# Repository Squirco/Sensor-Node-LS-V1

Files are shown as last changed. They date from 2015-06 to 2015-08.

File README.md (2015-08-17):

#Squirco Sensor Network Light Switch

Hardware files for Squirco Sensor Network Light Switch, as seen on Hackaday here:  
https://hackaday.io/project/3321-squirco-smart-home-system-sensor-network  
  
#Repository Contents
* **/Hardware-Main** - Eagle design files for the Logic and Power Supply boards (.sch and .brd)
* **/Hardware-Addon** - Eagle design files for the button, sensor, and programming adaptor boards (.sch and .brd)
* **/Hardware-3D** - 3D files for the enclosure. Designed to be 3D printed, tested with Form1+ and Shapeways/Sculpteo
* **/Hardware-Extras** - Contains BOM and other documents
* **/Firmware** - contains firmware files
  
#License Information
The hardware is released under <a href = "https://creativecommons.org/licenses/by-sa/4.0/">CC BY-SA 4.0</a>  
Hardware authors: Original Design by Steven @ Squirco
Distributed as-is; no warranty is given

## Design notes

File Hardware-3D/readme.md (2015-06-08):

#Squirco Sensor Network Light Switch
3D files are for the Open Edition, which are designed to be 3D printed  
Printed are tested with the following 3D printers and 3D printing services:
*formlabs Form1+
*Shapeways
*Sculpteo

Your mileage may vary depending on the 3D printer used. Parts can be purchased from Shapeways at a later date.

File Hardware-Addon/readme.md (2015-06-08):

#Squirco Sensor Light Switch Addons
Button board is designed for 1.6mm thickness. Ambient light sensor board is designed for 1.6mm thickness or below, ideally as thin as possible.

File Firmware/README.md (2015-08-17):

#Squirco Sensor Network Light Switch

Firmware files for Squirco Sensor Network Light Switch as a Atmel Studio 6 Project.

#Release Notes
- v0.5b
Initial commit after re-write from v0.4c. Some features have been re-written to work more efficiently. Some features have been removed for further re-write.

Working features:
- Light switch control, both hardware and from remote software
- Temperature measurement
- Ambient light measurement
- Networking and System Join Chain

Features to be re-implemented:
- on-device sync mode
- LED control
- Presence Detection

Features under experimentation
- OTA update

Further documentation will be added in time.

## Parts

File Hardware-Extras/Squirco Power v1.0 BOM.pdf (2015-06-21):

Squirco Power BOM
Count | Part Name | Value | Description | Size | Part Number | MFR
3 D1 D2 D3 | RS1KB-‐13-‐F | DIODE GEN PURP 800V 1A SMB | SMB | RS1KB-‐13-‐F | Diodes
1 F1 | FUSE BOARD MNT 1A 250VAC 125VDC | 10.10mm x 3.00mm 3403.0166.11 | Schurter
1 J1* | Micro USB connector | std
1 JP2 | CONN TERM BLOCK 3POS 5MM STR PCB | 1825970000 | Weidmuller
1 P1 | 3W AC-‐DC Converter | VTX-‐214-‐003-‐105 | Vigortronix
1 Q1 | BSS138 | MOSFET N-‐CH 50V 220MA SOT-‐23 | SOT23 | BSS138 | std
1 R11 | 39 | RES SMD 39 OHM 1% 1/10W 0603 | 0603 | std | std
1 S1 | ALQ305 | RELAY GEN PURPOSE SPST 10A 5V | ALQ305 | Panasonic
3 SC1 | P1 P2 P4 | MICRO UNIVERSAL CONTACT Z 4.0MM | 120220-‐0315 | ITT Cannon

Notes:
1. J1 is only needed for development prototypes as an alternate power source

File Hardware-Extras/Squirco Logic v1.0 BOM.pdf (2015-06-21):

Squirco Logic BOM
Count | Part Name | Value | Description | Size | Part Number | MFR
1 B1 | BALUN | Impedance matched Balun for ATMEGARFR2 | 2mm x 1.25mm 2450BM15A0015E | Johanson
1 B2 | BALUN | Impedance matched Balun for CC2541 | 2mm x 1.25mm 2450BM15A0002E | Johanson
4 C10 C13 C15 C21 12pF | CAP CER 12PF 50V 5% NPO 0402 | 0402 | std | std
2 C8 C12 | 22pF | CAP CER 22PF 50V 5% NPO 0402 | 0402 | std | std
1 C16 | 1nF | MLCC -‐ SMD/SMT 0603 1000pF 50V X7R 10% | 0603 | std | std
1 C6 | 10nF | MLCC -‐ SMD/SMT 0603 0.01uF 50V X7R 10% | 0603 | std | std
1 C2 | 0.1uF | MLCC -‐ SMD/SMT 0603 0.1uF 25V X7R 10% | 0603 | std | std
4 C1 C7 C14 C20 | 1uF | MLCC -‐ SMD/SMT 1.0UF 16V 10% | 0603 | std | std
3 C3 C5 C9 | 2.2uF | MLCC -‐ SMD/SMT 2.2UF 6.3V 10% | 0603 | std | std
1 C4 | DNI
1 D1 | WS2812B | Addressable RGB LED | 5050 | WS2812B | Worldsemi
1 LED1* | LED0805 | Power indicating LED (red) | 0805 | std | std
2 R1 R12 | 0R | 0R resistor | 0402 | std | std
1 R15 | 2k7 | SMD 1/10watt 2.7Kohms 1% | 0603 | std | std
2 R3 R8 | 4k7 | SMD 1/10watt 4.7Kohms 1% | 0603 | std | std
1 R14 | 10k | SMD 1/10watts 10Kohms 1% | 0603 | std | std
1 R9 | 56k | SMD 1/10watts 56Kohms 1% | 0603 | std | std
1 R4* | 510 current limiting resistor for LED1 | 0603 | std | std
1 R7 | 10k NTC | NTC 10K OHM 1% | 0402 | NCP15XH103F03RC | Murata
4 R2 R10 R11 R13 DNI | Footprints for RF filter passives | 0402 | std | std
1 IC1 | LP2985 | LDO Voltage Regulators 150-‐mA Low-‐Noise 1.5% SOT23-‐5L | LP2985-‐33DBVR | Texas Instruments
1 U3 | ATMEGARFR2 ATMEGA256RFR2 | QFN64 | ATMEGA256RFR2 | Atmel
1 U4 | CC2541 | CC2541 | VQFN40 | CC2541 | Texas Instruments
1 Y1 | 16MHz | CRYSTAL 16.0000MHZ 10PF SMD | SMD | ABM10-‐16.000MHZ-‐D30-‐T3 Abracon
1 Y3 | 32.768kHz | CRYSTAL 32.7680KHZ 12.5PF SMD | SMD | ABS07-‐32.768KHZ-‐T | Abracon
1 Y4 | 32MHz | CRYSTAL 32.0000MHZ 10PF SMD | SMD | FA-‐20H 32.0000MF20X-‐K3 Epson
2 | | | 3 x 1.27mm pin header | PTH | std | std

Notes:
1. LED1 can be chosen as any colour, or not mounted at all. The reference design uses a red LED
2. Adjust value of R4 to suit LED1 accordingly

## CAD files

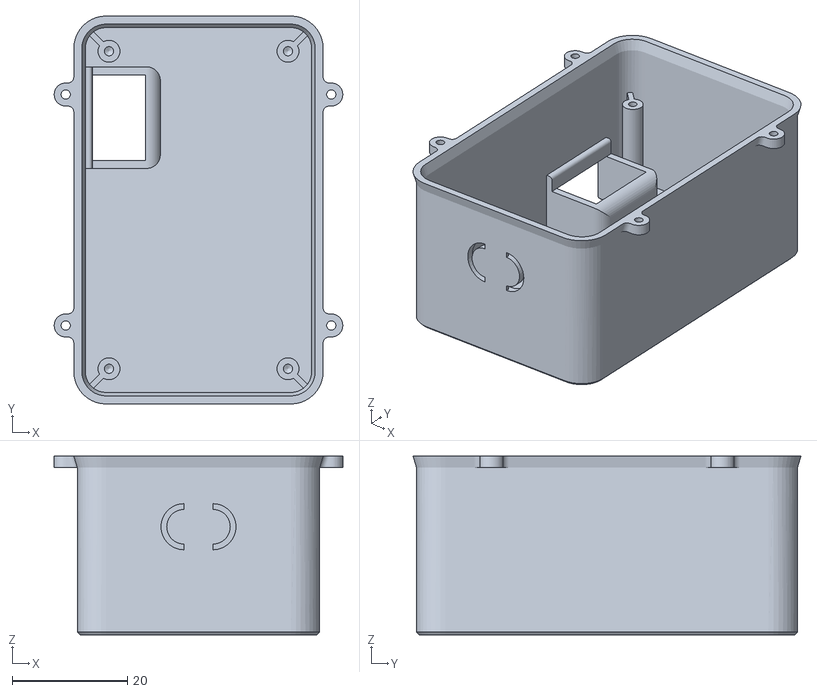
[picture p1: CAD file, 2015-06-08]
Hardware-3D/Squirco Sensor Node - Box.STL
50.0 x 67.2 x 31.0

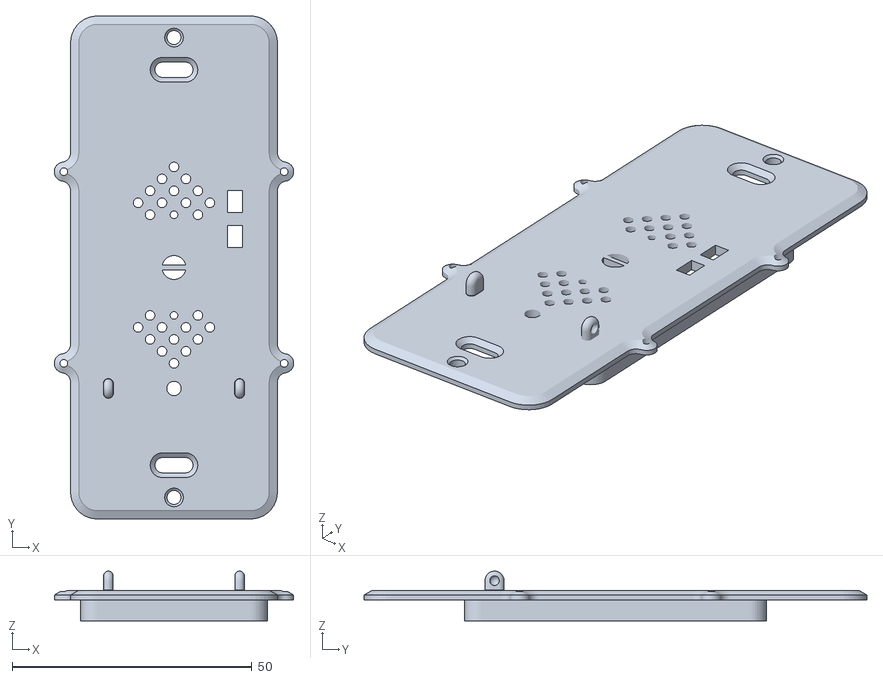
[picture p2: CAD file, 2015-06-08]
Hardware-3D/Squirco Sensor Node - Backplate.STL
50.0 x 105.0 x 10.4

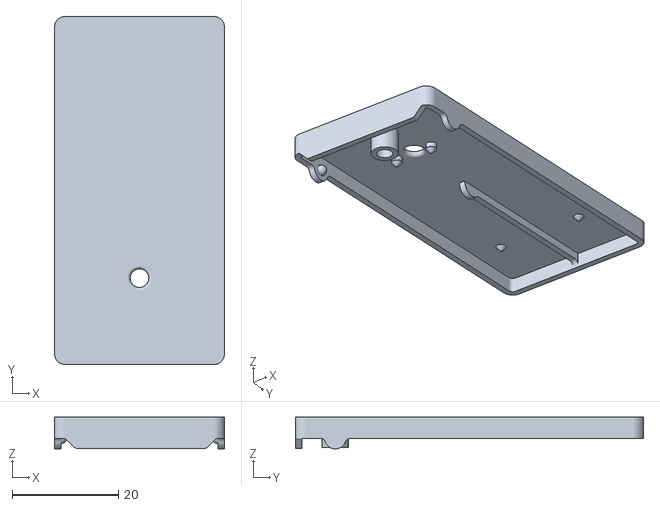
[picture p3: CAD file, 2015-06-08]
Hardware-3D/Squirco Sensor Node - Button.STL
32.0 x 65.5 x 6.00

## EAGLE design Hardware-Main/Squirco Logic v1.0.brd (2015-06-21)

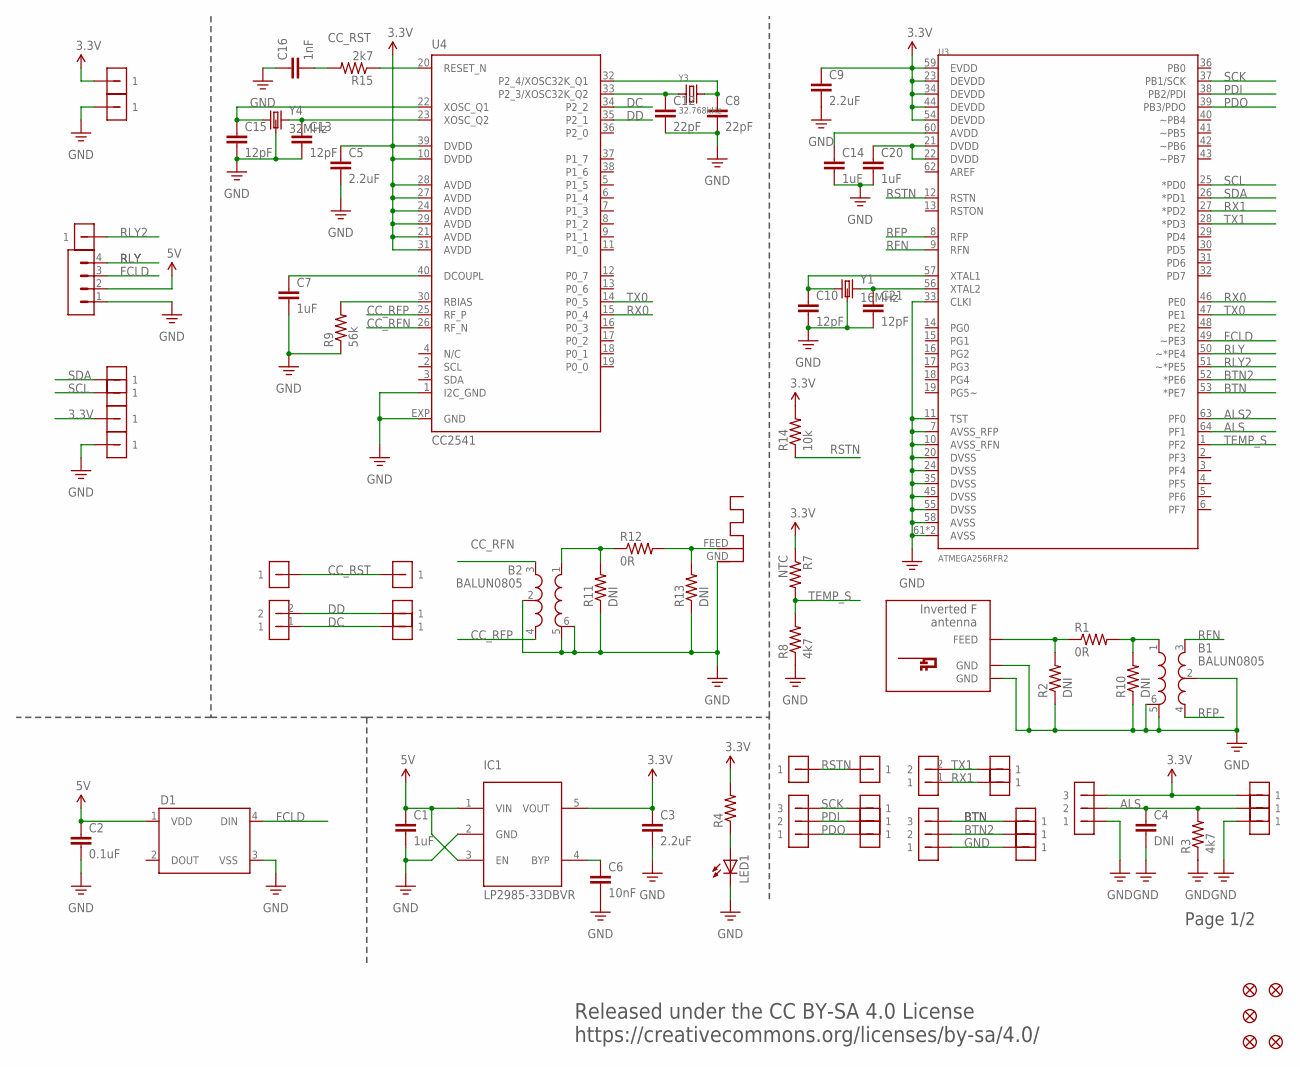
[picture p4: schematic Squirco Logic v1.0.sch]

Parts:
ANT1: ANTENNA; RN-ANT
ANT2: INVERTED_F_ANTENNA+5; DN007+5
B1, B2: BALUN0805; BALUN-2-4GHZ
C1, C7, C14, C20: 1uF; 0603-CAP
C2: 0.1uF; 0603-CAP
C3, C5, C9: 2.2uF; 0603-CAP
C4: DNI; 0603-CAP
C6: 10nF; 0603-CAP
C8, C12: 22pF; 0402-CAP
C10, C13, C15, C21: 12pF; 0402-CAP
C16: 1nF; 0603-CAP
D1: WS2812B
FID1, FID2, FID3, FID5, FID6: FIDUCIALUFIDUCIAL; MICRO-FIDUCIAL
IC1: LP2985-33DBVR; SOT23-5L
JP1: M02
LED1: LEDCHIP-LED0805; CHIP-LED0805
R1, R12: 0R; R0402
R2, R10, R11, R13: DNI; R0402
R3, R8: 4k7; R0603
R4: RESISTOR0603; 0603-RES
R7: NTC; R0402
R9: 56k; R0603
R14: 10k; R0603
R15: 2k7; R0603
U3: ATMEGA256RFR2; QFN-64
U4: CC2541; RHA_S-PVQFN-N40
U$4, U$6, U$25: M03
U$5: S04-4MM
U$7, U$8: M01
U$9: M02
U$10, U$11, U$12, U$13, U$14, U$15, U$16, U$17, U$18, U$19, U$20, U$21, U$22, U$23, U$24, U$26, U$27, U$30, U$31, U$34: S01C-4MM
U$32, U$33: S01-4MM
Y1: 16MHz; CRYSTAL-SMD-2.5X2-ABM10
Y3: 32.768kHz; ABS07
Y4: 32MHz; CRYSTAL-SMD-2.5X2-ABM10

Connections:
3.3V: C3.1, C5.1, C9.1, IC1.5 (VOUT), R4.2, R7.1, R14.2, U3.23 (DEVDD), U3.34 (DEVDD), U3.44 (DEVDD), U3.54 (DEVDD), U3.59 (EVDD), U4.10 (DVDD), U4.21 (AVDD), U4.24 (AVDD), U4.27 (AVDD), U4.28 (AVDD), U4.29 (AVDD), U4.31 (AVDD), U4.39 (DVDD), U$20.P$1, U$25.3, U$26.P$1, U$30.P$1
5V: C1.1, C2.1, D1.1 (VDD), IC1.1 (VIN), IC1.3 (EN), U$5.2
ALS: C4.1, R3.2, U3.64 (PF1), U$25.2, U$31.P$1
ALS2: U3.63 (PF0)
BTN: U3.53 (*PE7), U$6.3, U$22.P$1
BTN2: U3.52 (*PE6), U$6.2, U$23.P$1
CC_RFN: B2.3, U4.26 (RF_N)
CC_RFP: B2.4, U4.25 (RF_P)
CC_RST: C16.2, R15.2, U$8.1, U$17.P$1
DC: U4.34 (P2_2), U$9.1, U$19.P$1
DD: U4.35 (P2_1), U$9.2, U$18.P$1
FCLD: D1.4 (DIN), U3.49 (~PE3), U$5.3
GND: ANT1.GND, ANT2.GND, ANT2.GND@1 (GND), B1.2, B1.5, B1.6, B2.2, B2.5, B2.6, C1.2, C2.2, C3.2, C4.2, C5.2, C6.2, C7.2, C8.2, C9.2, C10.2, C12.2, C13.2, C14.2, C15.2, C16.1, C20.2, C21.2, D1.3 (VSS), IC1.2 (GND), LED1.C, R2.1, R3.1, R8.1, R9.1, R10.1, R11.1, R13.1, U3.7 (AVSS_RFP), U3.10 (AVSS_RFN), U3.11 (TST), U3.20 (DVSS), U3.24 (DVSS), U3.33 (CLKI), U3.35 (DVSS), U3.45 (DVSS), U3.55 (DVSS), U3.58 (AVSS), U3.61 (AVSS), U3.PADDLE (AVSS), U4.1 (I2C_GND), U4.EXP (GND), U$5.1, U$6.1, U$21.P$1, U$25.1, U$27.P$1, U$32.P$1, U$33.P$1, Y1.P$2 (GND), Y1.P$4 (GND), Y4.P$2 (GND), Y4.P$4 (GND)
unnamed: C10.1, U3.57 (XTAL1), Y1.P$1 (1)
unnamed: C21.1, U3.56 (XTAL2), Y1.P$3 (2)
unnamed: LED1.A, R4.1
unnamed: ANT2.FEED, R1.1, R2.2
unnamed: C6.1, IC1.4 (BYP)
unnamed: C7.1, U4.40 (DCOUPL)
unnamed: C20.1, U3.21 (DVDD), U3.22 (DVDD)
unnamed: C14.1, U3.60 (AVDD)
unnamed: R9.2, U4.30 (RBIAS)
unnamed: B2.1, R11.2, R12.1
unnamed: ANT1.FEED, R12.2, R13.2
unnamed: C15.1, U4.22 (XOSC_Q1), Y4.P$1 (1)
unnamed: C13.1, U4.23 (XOSC_Q2), Y4.P$3 (2)
unnamed: C8.1, U4.32 (P2_4/XOSC32K_Q1), Y3.2
unnamed: B1.1, R1.2, R10.2
unnamed: C12.1, U4.33 (P2_3/XOSC32K_Q2), Y3.1
unnamed: R15.1, U4.20 (RESET_N)
N/C: U4.4 (N/C)
PDI: U3.38 (PB2/PDI), U$4.2, U$13.P$1
PDO: U3.39 (PB3/PDO), U$4.1, U$14.P$1
RFN: B1.3, U3.9 (RFN)
RFP: B1.4, U3.8 (RFP)
RLY: U3.50 (~*PE4), U$5.4
RLY2: U3.51 (~*PE5), U$34.P$1
RSTN: R14.1, U3.12 (RSTN), U$7.1, U$11.P$1
RX0: U3.46 (PE0), U4.15 (P0_4)
RX1: JP1.1, U3.27 (*PD2), U$16.P$1
SCK: U3.37 (PB1/SCK), U$4.3, U$12.P$1
SCL: U3.25 (*PD0), U$24.P$1
SDA: U3.26 (*PD1), U$10.P$1
TEMP_S: R7.2, R8.2, U3.1 (PF2)
TX0: U3.47 (PE1), U4.14 (P0_5)
TX1: JP1.2, U3.28 (*PD3), U$15.P$1

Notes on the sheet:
Page 1/2
Released under the CC BY-SA 4.0 License https://creativecommons.org/licenses/by-sa/4.0/

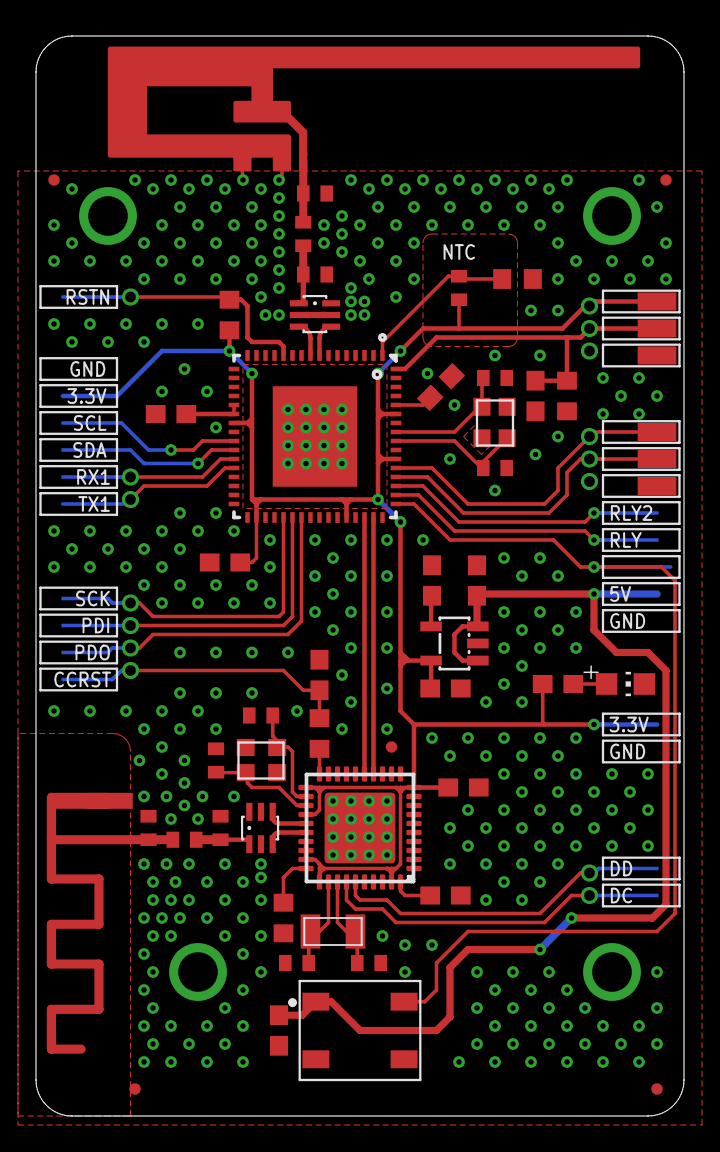
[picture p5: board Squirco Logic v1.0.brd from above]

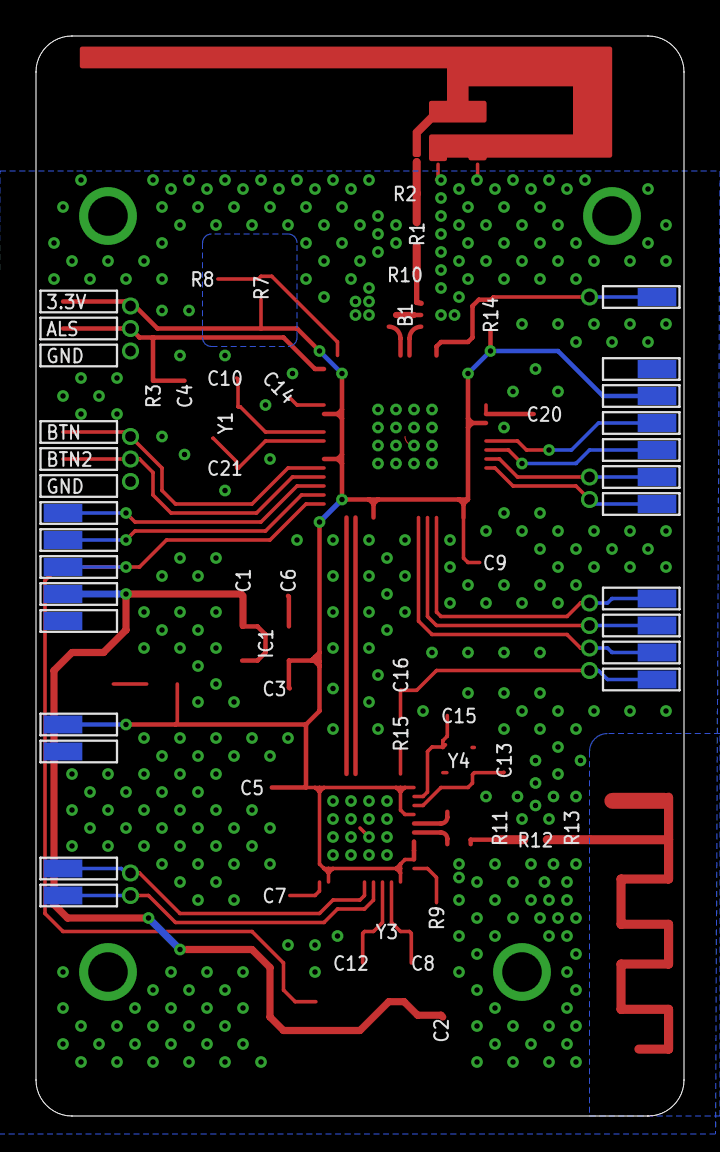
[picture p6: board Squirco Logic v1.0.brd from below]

Board: 2 copper layers, 36.0 x 60.0 mm, 77 parts (17 on the bottom side), 44 nets.

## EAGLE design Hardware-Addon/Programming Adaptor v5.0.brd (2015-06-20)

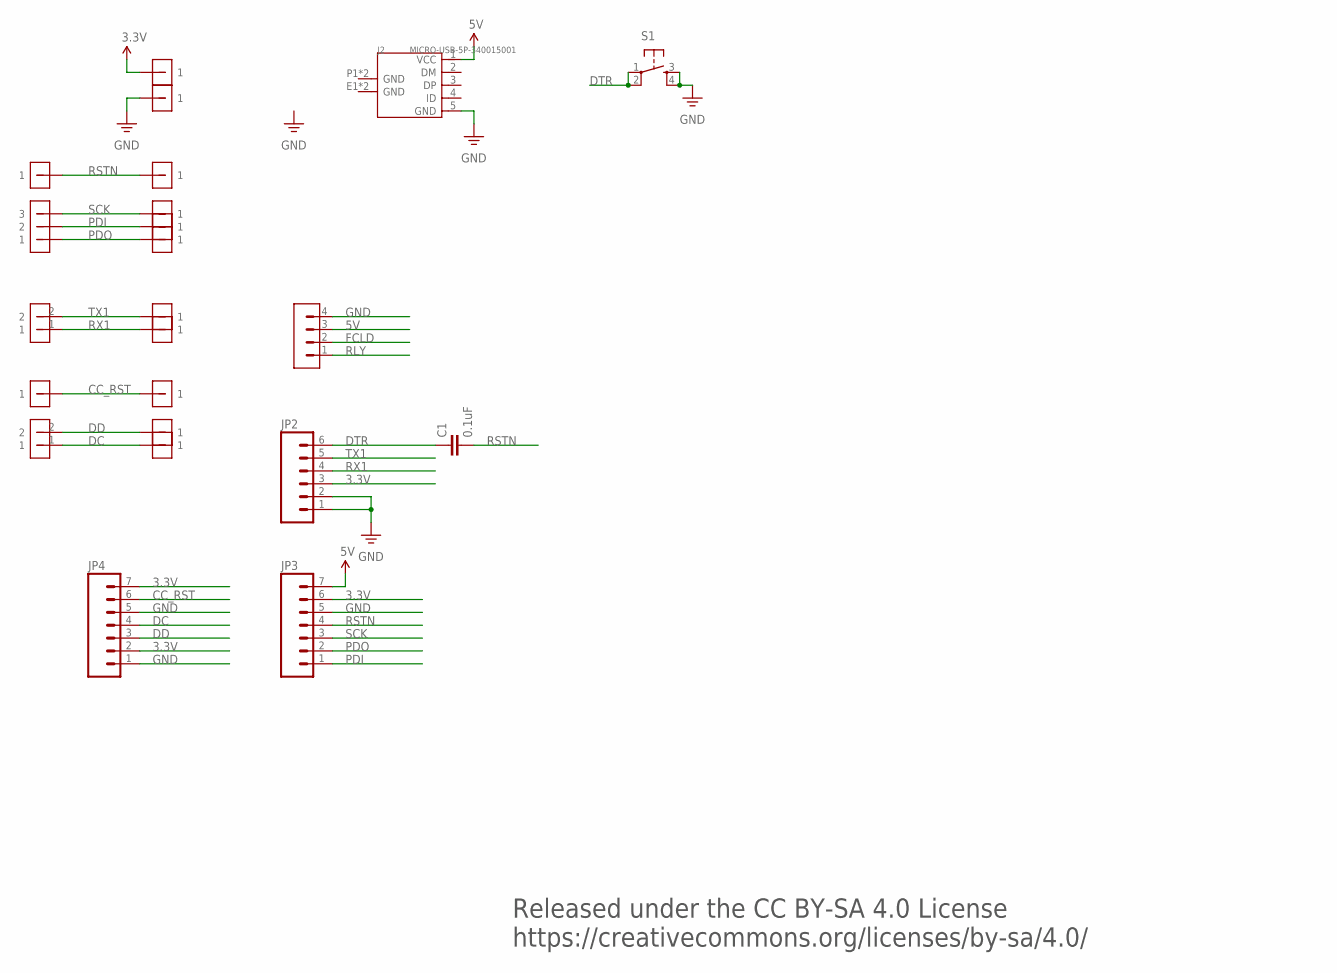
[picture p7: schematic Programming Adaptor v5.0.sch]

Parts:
C1: 0.1uF; 0603-CAP
J2: MICRO-USB-5P-340015001; B-SMD-5P
JP1: M02
JP2: M06LOCK; 1X06_LOCK
JP3, JP4: M07; 1X07
S1: TAC_SWITCHSMD; TACTILE-SWITCH-SMD
U$4: M03
U$5: S04-4MM
U$7, U$8: M01
U$9: M02
U$11, U$12, U$13, U$14, U$15, U$16, U$17, U$18, U$19, U$20, U$21: S01C-4MM

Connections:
3.3V: JP2.3, JP3.6, JP4.2, JP4.7, U$20.P$1
5V: J2.1 (VCC), JP3.7, U$5.3
CC_RST: JP4.6, U$8.1, U$17.P$1
DC: JP4.4, U$9.1, U$19.P$1
DD: JP4.3, U$9.2, U$18.P$1
DTR: C1.1, JP2.6, S1.1, S1.2
FCLD: U$5.2
GND: J2.5 (GND), JP2.1, JP2.2, JP3.5, JP4.1, JP4.5, S1.3, S1.4, U$5.4, U$21.P$1
PDI: JP3.1, U$4.2, U$13.P$1
PDO: JP3.2, U$4.1, U$14.P$1
RLY: U$5.1
RSTN: C1.2, JP3.4, U$7.1, U$11.P$1
RX1: JP1.1, JP2.4, U$16.P$1
SCK: JP3.3, U$4.3, U$12.P$1
TX1: JP1.2, JP2.5, U$15.P$1

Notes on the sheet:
Released under the CC BY-SA 4.0 License https://creativecommons.org/licenses/by-sa/4.0/

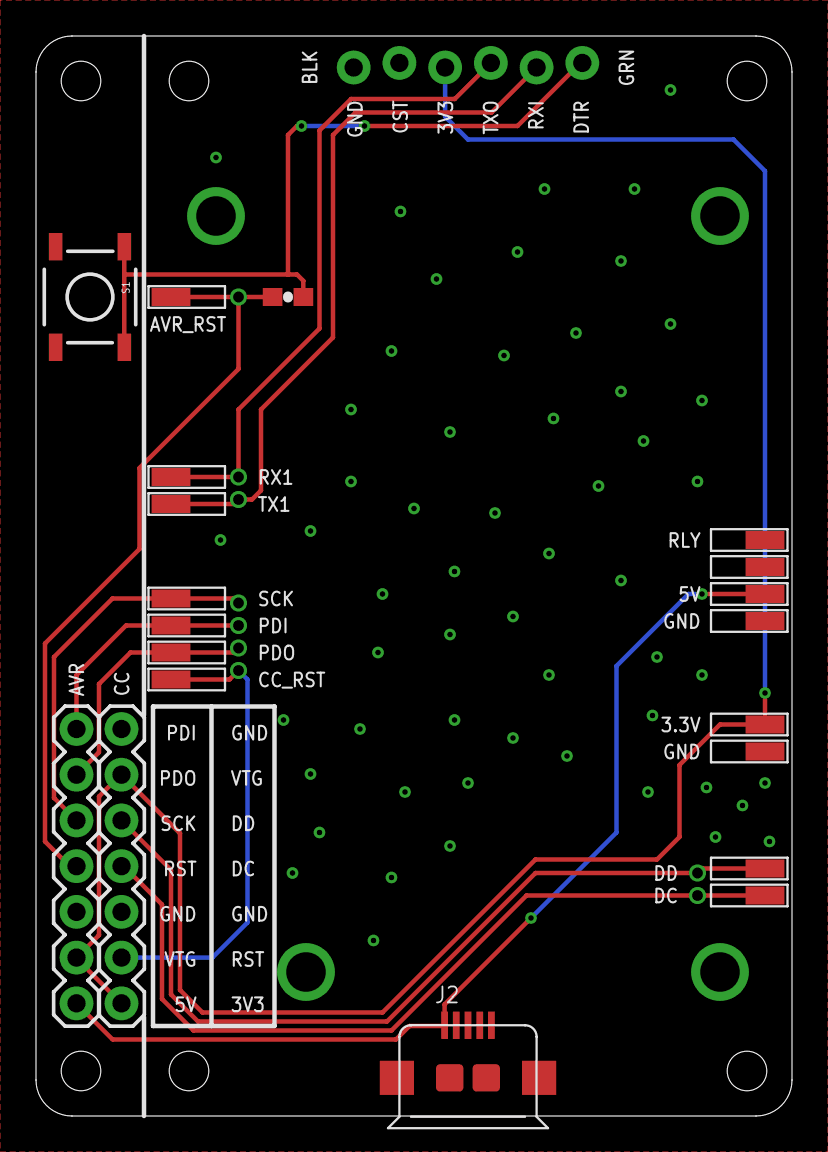
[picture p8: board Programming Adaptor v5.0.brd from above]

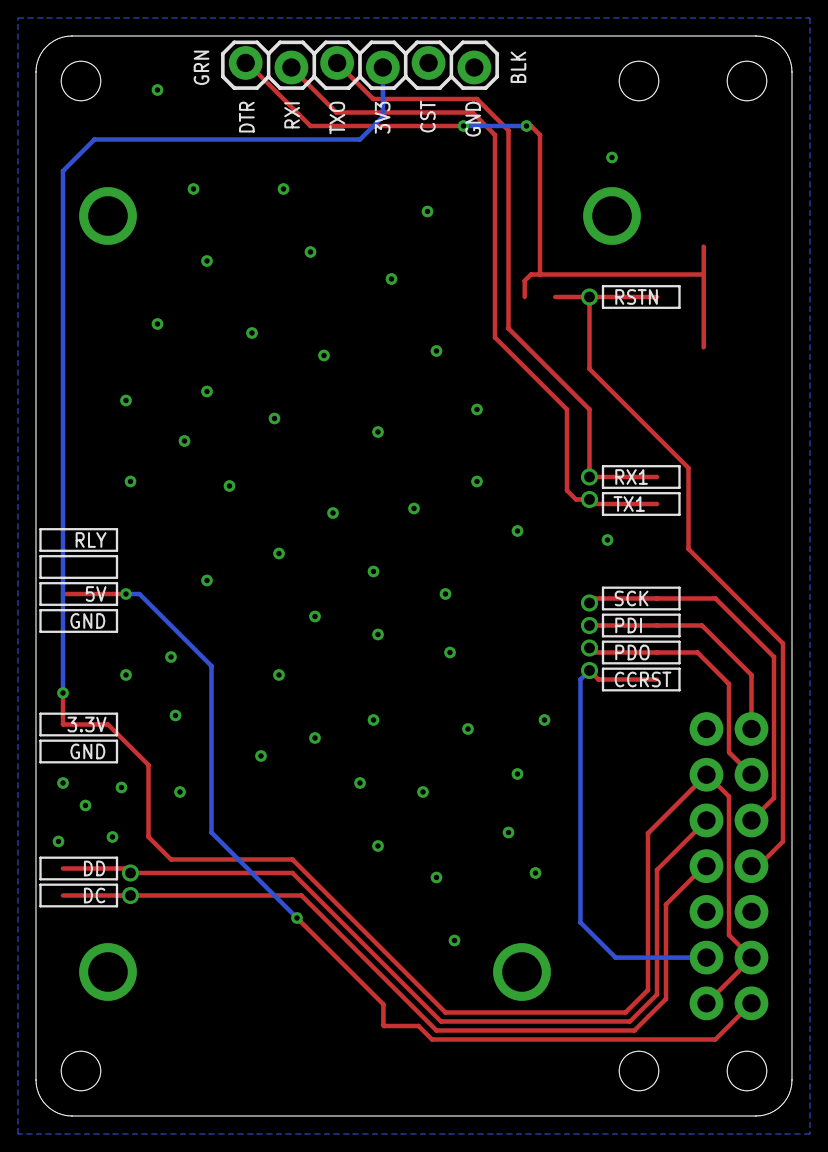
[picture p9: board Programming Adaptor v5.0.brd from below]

Board: 2 copper layers, 42.0 x 60.0 mm, 23 parts (2 on the bottom side), 13 nets.

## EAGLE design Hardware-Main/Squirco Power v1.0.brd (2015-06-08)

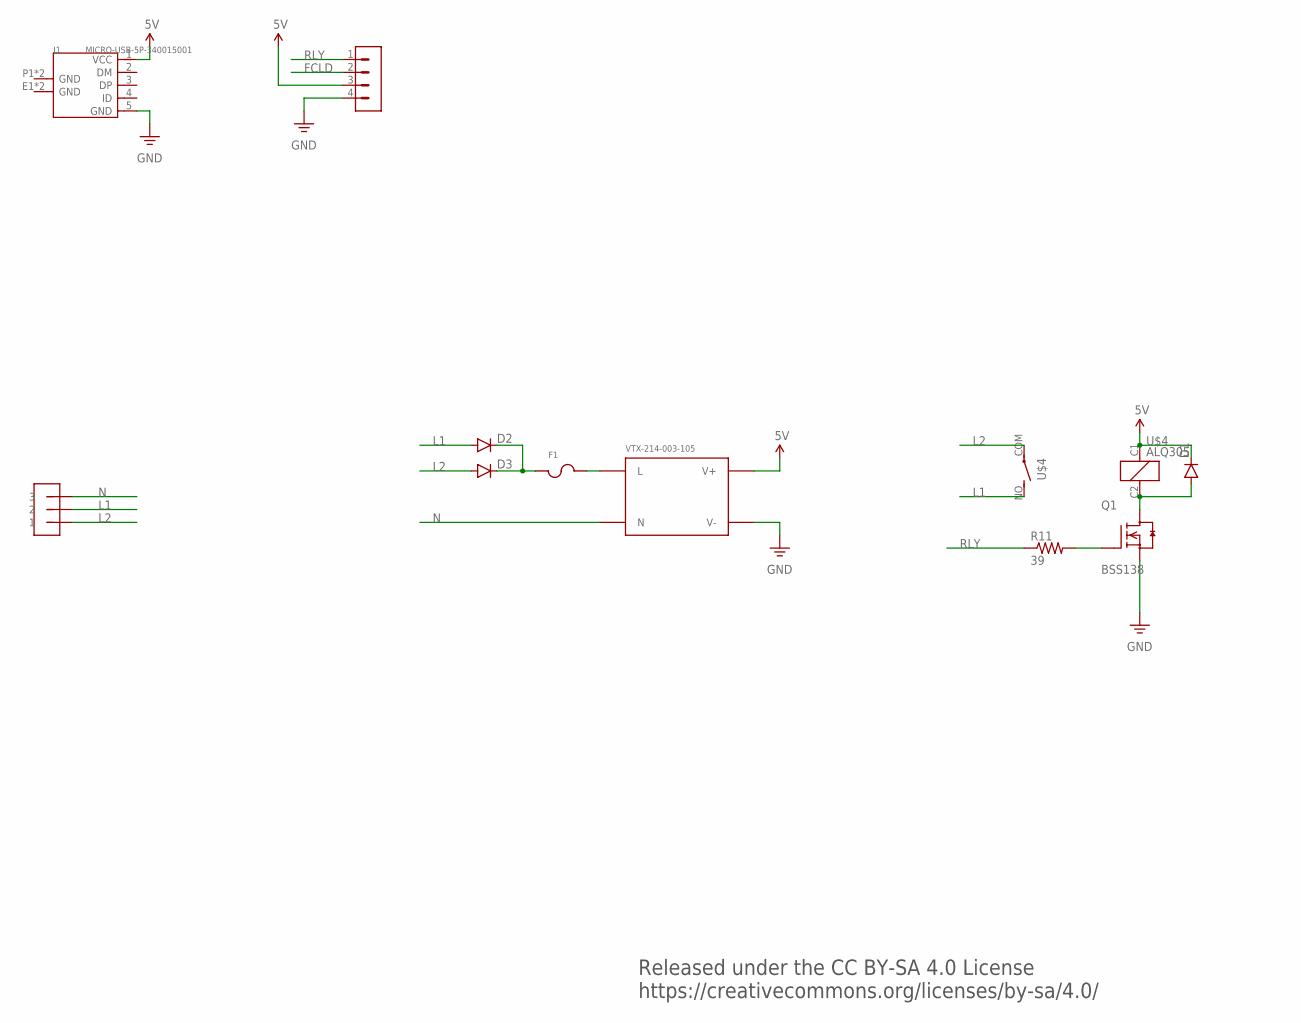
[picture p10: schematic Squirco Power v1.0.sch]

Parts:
D1, D2, D3: DIODESMB; SMB-DIODE
F1: UMT250
J1: MICRO-USB-5P-340015001; B-SMD-5P
JP2: LSF-SMT5; LF-SMT5
Q1: BSS138; SOT23
R11: 39; 0603-RES
U$1: VTX-214-003-105; VTX-214-003-1XX
U$3: S04-4MM
U$4: ALQ305

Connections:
5V: D1.C, J1.1 (VCC), U$1.3 (V+), U$3.3, U$4.C1 (1)
FCLD: U$3.2
GND: J1.5 (GND), Q1.2 (S), U$1.4 (V-), U$3.4
L1: D2.A, JP2.3 (2), JP2.4 (2), U$4.NO (S)
L2: D3.A, JP2.1, JP2.2 (1), U$4.COM
N: JP2.5 (3), JP2.6 (3), U$1.1 (N)
unnamed: F1.P$2, U$1.2 (L)
unnamed: Q1.1 (G), R11.2
unnamed: D2.C, D3.C, F1.P$1
unnamed: D1.A, Q1.3 (D), U$4.C2 (2)
RLY: R11.1, U$3.1

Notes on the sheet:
Released under the CC BY-SA 4.0 License https://creativecommons.org/licenses/by-sa/4.0/

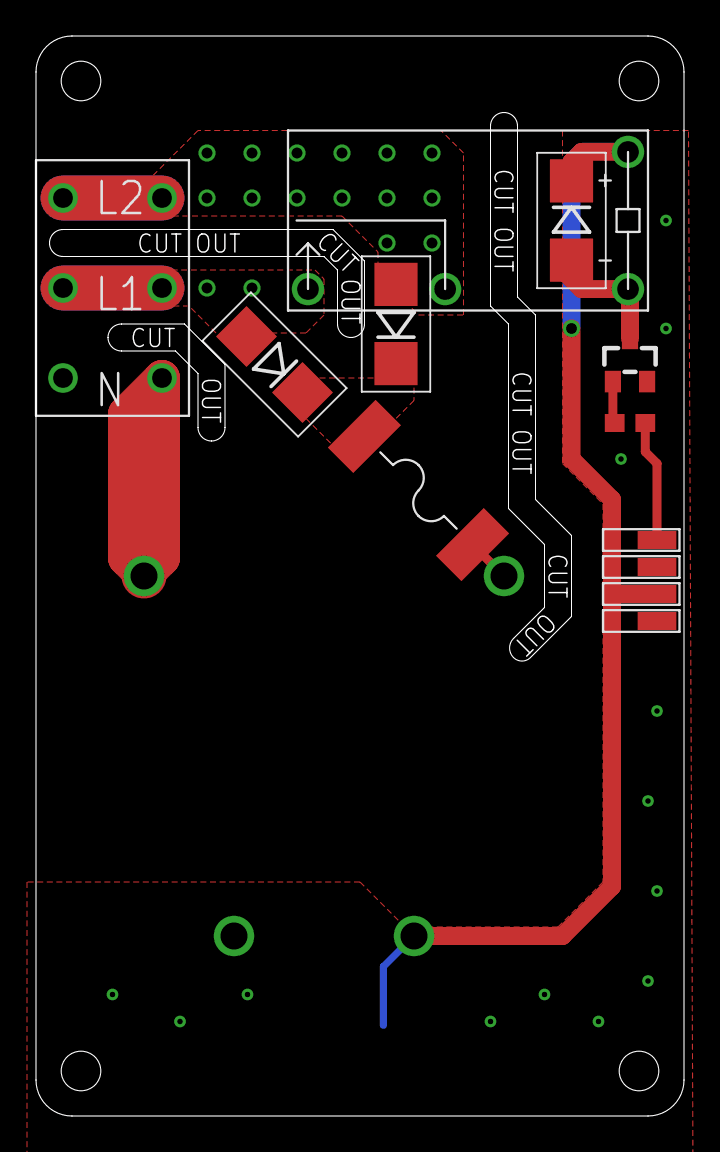
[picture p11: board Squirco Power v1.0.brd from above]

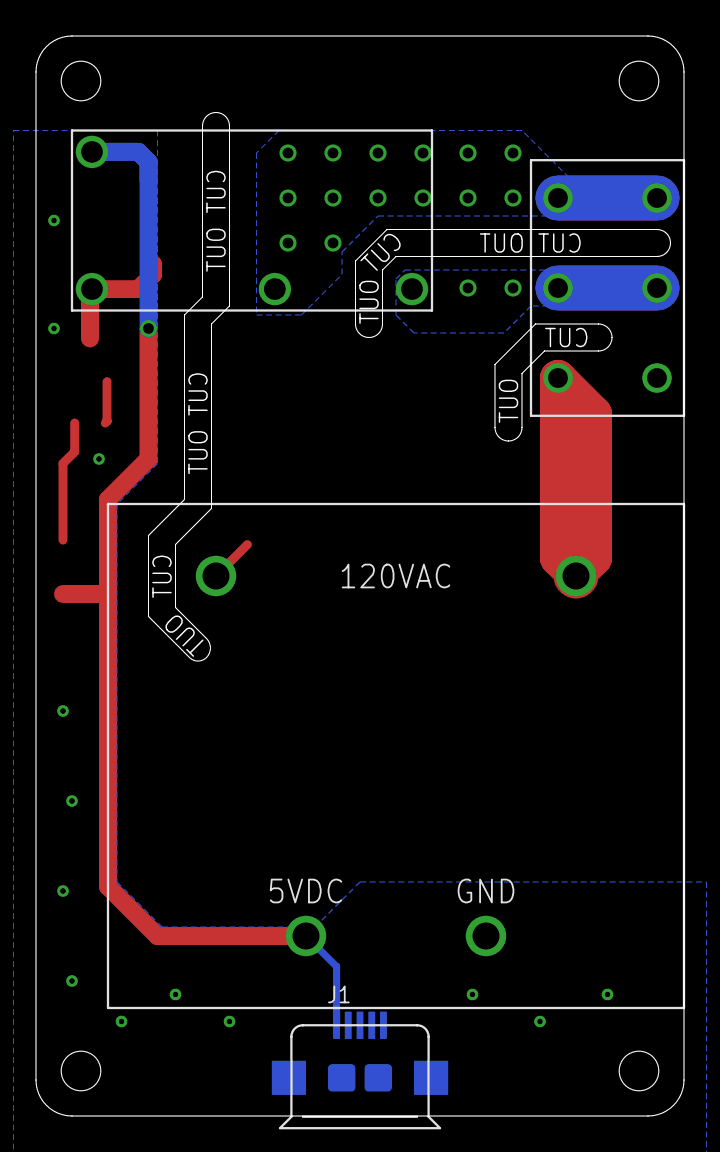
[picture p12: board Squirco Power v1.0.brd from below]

Board: 2 copper layers, 36.0 x 60.0 mm, 11 parts (2 on the bottom side), 10 nets.

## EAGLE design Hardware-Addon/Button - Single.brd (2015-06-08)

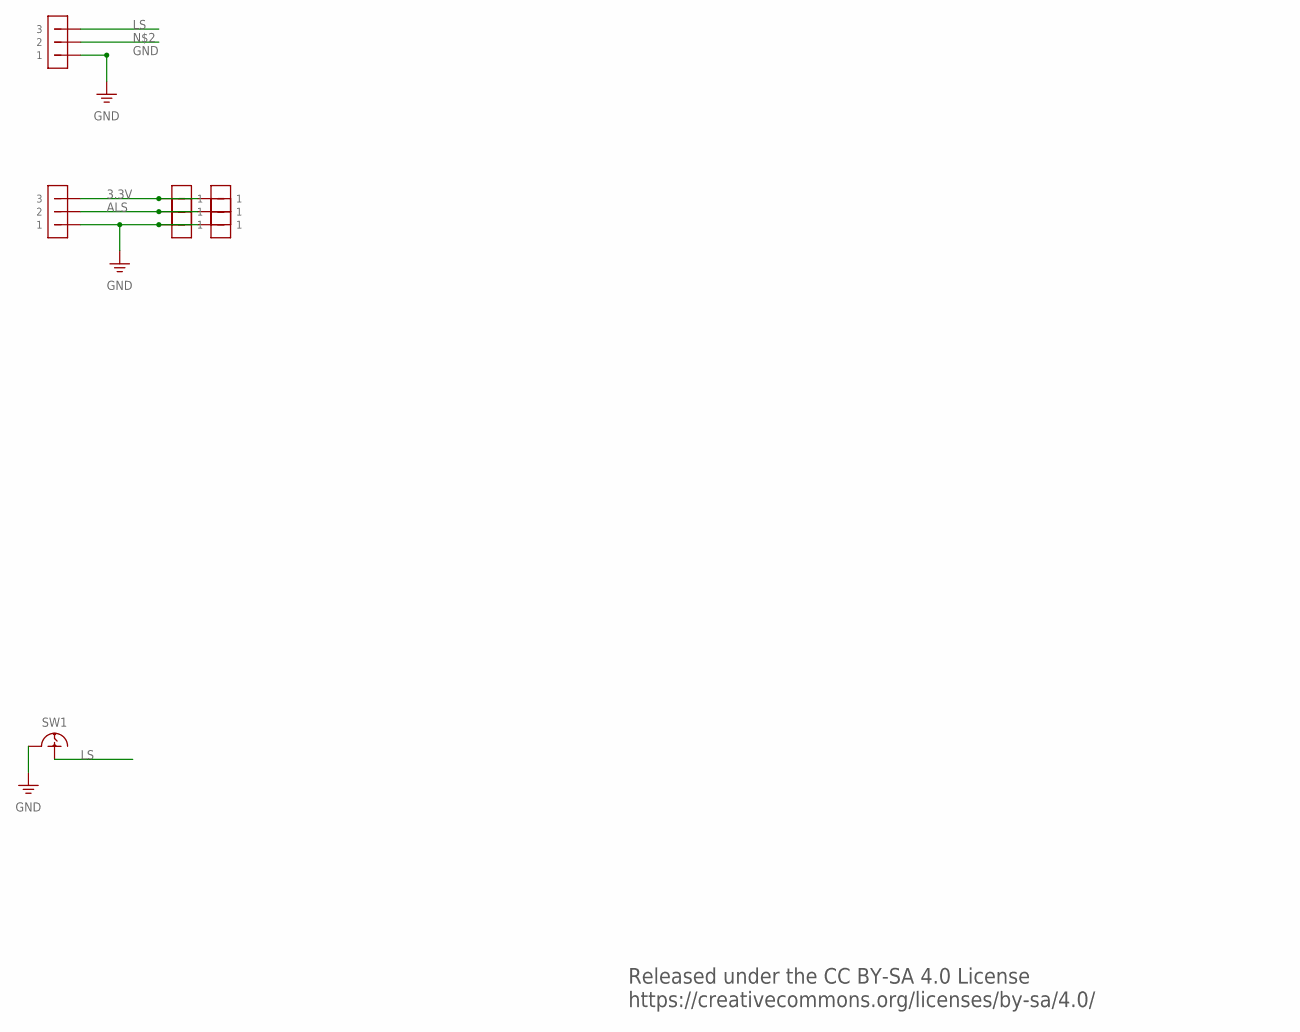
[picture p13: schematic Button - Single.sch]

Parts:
SW1: U12390; UFTCGX12
U$1, U$2: M03
U$3, U$4, U$5, U$6, U$7, U$8: S01-4MM

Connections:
3.3V: U$1.3, U$3.P$1, U$6.P$1
ALS: U$1.2, U$4.P$1, U$7.P$1
GND: SW1.GND, U$1.1, U$2.1, U$5.P$1, U$8.P$1
LS: SW1.SIG, U$2.3

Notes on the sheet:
Released under the CC BY-SA 4.0 License https://creativecommons.org/licenses/by-sa/4.0/

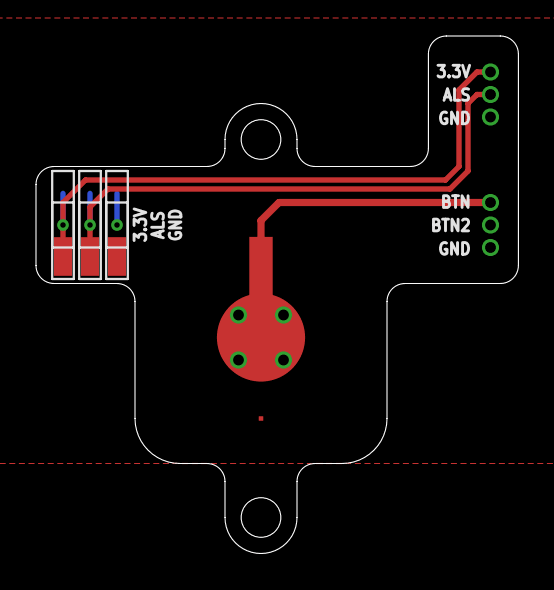
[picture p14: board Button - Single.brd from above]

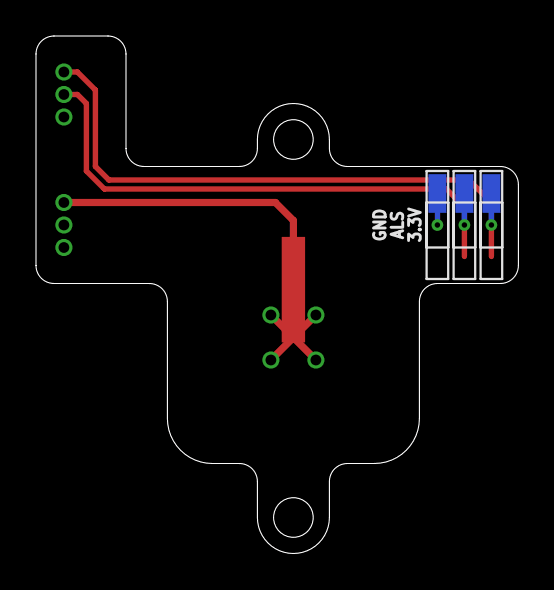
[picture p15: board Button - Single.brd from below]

Board: 2 copper layers, 26.8 x 28.8 mm, 9 parts (3 on the bottom side), 4 nets.

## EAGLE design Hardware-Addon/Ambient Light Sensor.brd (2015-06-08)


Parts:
U1: ADPS-9004; APDS-9004
U$2, U$3, U$4: S01-4MM

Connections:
3.3V: U1.2 (VCC), U1.3 (VCC), U$2.P$1
ALS: U1.1 (OUT), U$3.P$1
GND: U$4.P$1

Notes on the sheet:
Released under the CC BY-SA 4.0 License https://creativecommons.org/licenses/by-sa/4.0/



Board: 2 copper layers, 18.0 x 5.0 mm, 4 parts (3 on the bottom side), 2 nets.

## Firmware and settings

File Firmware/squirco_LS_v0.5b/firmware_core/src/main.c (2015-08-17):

/*- Includes ---------------------------------------------------------------*/
#include "main.h"

/*- Definitions ------------------------------------------------------------*/
#ifdef NWK_ENABLE_SECURITY
	#define APP_BUFFER_SIZE     (NWK_MAX_PAYLOAD_SIZE - NWK_SECURITY_MIC_SIZE)
#else
	#define APP_BUFFER_SIZE     NWK_MAX_PAYLOAD_SIZE
#endif

//system settings stored in EEPROM
//Production values are loaded separately after programming chip

uint32_t EEMEM eeSerialNum = 0x00000001;	//serial number
uint16_t EEMEM eeHardVersion = 0x007a;		//hardware version
uint32_t EEMEM eeSecurityKeyH = 0x0848A357;	//upper 32 bits of security key. Security will be upgraded at a later time.
uint32_t EEMEM eeSecurityKeyL = 0x9D256556;	//lower 32 bits of security key.
uint16_t EEMEM eeIdentity;					//unique identity extension to avoid collision. Randomly generated at first startup.
uint16_t EEMEM eeShortAddr = 0x0001;		//short address. Will be randomly generated later.
uint16_t EEMEM eeDefaultPan = 0x1234;		//default pan address.
uint8_t EEMEM eeDefaultChannel = 0x0f;		//default channel. Channel scanning will be implemented later
//uint8_t EEMEM eeSysJoined = 1;
uint8_t EEMEM eeSysJoined = 0;				//Tracks whether the node has been connected to a hub or not

//system settings copied to memory during run time
uint32_t App_SerialNum;
uint64_t App_SecurityKey;
uint16_t App_Identity;
uint16_t App_ShortAddr;
uint16_t App_PanID;
uint8_t App_Channel;

AppState_t appState = APP_STATE_INITIAL;

NWK_DataReq_t	appNwkDataReq;
NWK_DataReq_t	appNwkBroadcastDataReq;
bool	appNwkDataReqBusy = false; 

//software Timers
SYS_Timer_t  appLSDebounceTimer;	//debounce timer
SYS_Timer_t  appDBTTimer;			//timer used to measure temperature
SYS_Timer_t	appALSTimer;			//timer used to measure ambient light
SYS_Timer_t	appRTCTimer;			//tick tock
SYS_Timer_t	appAsyncJoinTimer;		//delay timer to send join confirmation
SYS_Timer_t	appAsyncJoinChainResetTimer;	//delay timer to reset join chain state

/* Globals: Miscellaneous */
volatile uint16_t src_node;	//temporary storage variable for source address
volatile uint16_t dst_node; // temporary storage variable for destination address
volatile uint8_t  tx_tries = 0; // transmission retry tracker

//system Mode variables
volatile bool SYSModeSync = false;

/*- Implementations --------------------------------------------------------*/

static void appDataConf(NWK_DataReq_t *req)
{
	appNwkDataReqBusy = false; // clear the busy flag
	appState=APP_STATE_IDLE;
	(void)req;
}

static void appSystemJoinConf(NWK_DataReq_t *req)
{
	appNwkDataReqBusy = false; // clear the busy flag
	
	if (eeprom_is_ready())
	{
		eeprom_update_word((uint16_t*)&eeDefaultPan, App_PanID);
		eeprom_update_byte((uint8_t*)&eeSysJoined, 1);
	}
	
	if (!SYS_TimerStarted(&appDBTTimer))
	{
		SYS_TimerStart(&appDBTTimer);
	}
	
	if (!SYS_TimerStarted(&appALSTimer))
	{
		SYS_TimerStart(&appALSTimer);
	}
	
	LSConnectedMode = true;
	
	appState=APP_STATE_IDLE;
	(void)req;
}

static void appTempDataConf(NWK_DataReq_t *req)
{
	if ((tx_tries < APP_MAX_TX_RETRIES) && (req -> status & NWK_NO_ACK_STATUS))
	{
		tx_tries++;
		
		CommandsInBuffer[CommandsInIndexEnd][0] = 0x0181;	//get incoming command ID
		CommandsInBuffer[CommandsInIndexEnd][1] = HUB_ADDR;	//send to hub
		
		CommandsInIndexEnd++;
		if (CommandsInIndexEnd == CommandsInIndexSize)
		{
			CommandsInIndexEnd = 0;
		}
	}
	
	if (tx_tries >= APP_MAX_TX_RETRIES)
	{
		tx_tries = 0;
	}
	
	appNwkDataReqBusy = false; // clear the busy flag
	appState=APP_STATE_IDLE;
	(void)req;
}

static void appLightDataConf(NWK_DataReq_t *req)
{
	if ((tx_tries < APP_MAX_TX_RETRIES) && (req -> status & NWK_NO_ACK_STATUS))
	{
		tx_tries++;
		
		CommandsInBuffer[CommandsInIndexEnd][0] = 0x0182;	//get incoming command ID
		CommandsInBuffer[CommandsInIndexEnd][1] = HUB_ADDR;	//send to hub
			
		CommandsInIndexEnd++;
		if (CommandsInIndexEnd == CommandsInIndexSize)
		{
			CommandsInIndexEnd = 0;
		}
	}
	
	if (tx_tries >= APP_MAX_TX_RETRIES)
	{
		tx_tries = 0;
	}
		
	appNwkDataReqBusy = false; // clear the busy flag
	appState=APP_STATE_IDLE;
	(void)req;
}

static void appLSButtonDataConf(NWK_DataReq_t *req)
{
	if ((tx_tries < APP_MAX_TX_RETRIES) && (req -> status & NWK_NO_ACK_STATUS))
	{
		tx_tries++;
		
		CommandsInBuffer[CommandsInIndexEnd][0] = 0x0191;	//get incoming command ID
		CommandsInBuffer[CommandsInIndexEnd][1] = HUB_ADDR;	//send to hub
			
		CommandsInIndexEnd++;
		if (CommandsInIndexEnd == CommandsInIndexSize)
		{
			CommandsInIndexEnd = 0;
		}
	}
	
	if (tx_tries >= APP_MAX_TX_RETRIES)
	{
		tx_tries = 0;
	}
	
	appNwkDataReqBusy = false; // clear the busy flag
	appState=APP_STATE_IDLE;
	(void)req;
}

/*************************************************************************//**
*****************************************************************************/

static void appSendData(uint16_t node, uint8_t src_endpoint, uint8_t dst_endpoint)
{
	while (appNwkDataReqBusy == true)		// if a transmit request is already in progress
	{                                
							  // wait for transmission to finish
	}
	
	appNwkDataReq.dstAddr = node;
	appNwkDataReq.dstEndpoint = dst_endpoint;
	appNwkDataReq.srcEndpoint = src_endpoint;
	
	switch (CMDDataAckType)
	{
		case CMDACKMODEON:
		{
			appNwkDataReq.options = NWK_OPT_ACK_REQUEST | NWK_OPT_ENABLE_SECURITY;
			break;
		}
		case CMDACKMODEOFF:
		{
			appNwkDataReq.options = NWK_OPT_ENABLE_SECURITY;
			break;
		}
		
		default:
		{
			appNwkDataReq.options = NWK_OPT_ENABLE_SECURITY;
			break;
		}
	}
	
	switch (CMDDataConfType)
	{
		case CMDCONFGENERIC:	//generic conf
		{
			appNwkDataReq.confirm = appDataConf;
			break;
		}
		
		case CMDCONFSYSJOIN:	//system joined conf
		{
			appNwkDataReq.confirm = appSystemJoinConf;
			break;
		}
		
		case CMDCONFLSBUTTON:	//ls button
		{
			appNwkDataReq.confirm = appLSButtonDataConf;
			break;
		}
		
		case CMDCONFTEMP:	//temperature
		{
			appNwkDataReq.confirm = appTempDataConf;
			break;
		}
		
		case CMDCONFLIGHT:	//ambient light
		{
			appNwkDataReq.confirm = appLightDataConf;
			break;
		}
		
		default:
		{
			appNwkDataReq.confirm = appDataConf;
			break;
		}
	}
	
	NWK_DataReq(&appNwkDataReq);
	appNwkDataReqBusy = true;
	appState = APP_STATE_WAIT_CONF;
}

static void appBroadcastData(uint8_t src_endpoint, uint8_t dst_endpoint)
{
	while (appNwkDataReqBusy == true)		// if a transmit request is already in progress
	{
		// wait for transmission to finish
	}
	
	appNwkDataReq.dstAddr = NWK_BROADCAST_ADDR;
	appNwkDataReq.dstEndpoint = dst_endpoint;
	appNwkDataReq.srcEndpoint = src_endpoint;
	appNwkDataReq.options = NWK_OPT_BROADCAST_PAN_ID;// | NWK_OPT_ENABLE_SECURITY;
	appNwkDataReq.confirm = appDataConf;
	NWK_DataReq(&appNwkDataReq);
	appNwkDataReqBusy = true;
	appState = APP_STATE_WAIT_CONF;
}
/*************************************************************************//**
*****************************************************************************/
static bool appDataInd(NWK_DataInd_t *ind)
{
		//extract info from incoming message
		CommandsInBuffer[CommandsInIndexEnd][0] = ind->data[1] << 8 | ind->data[0];	//get incoming command ID
		CommandsInBuffer[CommandsInIndexEnd][1] = ind->srcAddr;	//get incoming node address
		CommandsInBuffer[CommandsInIndexEnd][2] = ind->data[3] << 8 | ind->data[2];	//get payload
		
		CommandsInIndexEnd++;
		if (CommandsInIndexEnd == CommandsInIndexSize)
		{
			CommandsInIndexEnd=0;
		}
	
	return true;
	appState = APP_STATE_IDLE;
}

static void appDBTTimerHandler(SYS_Timer_t *timer)
{
	ADC_GET_TEMPERATURE();
	(void)timer;
}

static void appLSDebounceTimerHandler(SYS_Timer_t *timer)
{
	LSDebounceSwitch();
	LSToggleQuiet();
	(void)timer;
}

static void appALSTimerHandler(SYS_Timer_t *timer)
{	
	ADC_GET_AMBIENT_LIGHT();
	(void)timer;
}

static void appAsyncJoinTimerHandler(SYS_Timer_t *timer)
{
	CommandsInBuffer[CommandsInIndexEnd][0] = 0x0101;	//get incoming command ID
	CommandsInBuffer[CommandsInIndexEnd][1] = 0;		//get incoming node address
	
	CommandsInIndexEnd++;
	if (CommandsInIndexEnd == CommandsInIndexSize)
	{
		CommandsInIndexEnd=0;
	}
	
	appState = APP_STATE_IDLE;
	(void)timer;
}

static void appAsyncJoinChainResetTimerHandler(SYS_Timer_t *timer)
{
	SysJoinChained = false;
}

static void appRTCTimerHandler(SYS_Timer_t *timer)
{
	LSModeCounter++;
	(void)timer;
}

static void appInit(void)
{   
    App_SerialNum = eeprom_read_dword(&eeSerialNum);
    App_SecurityKey = eeprom_read_dword(&eeSecurityKeyH);   //read the first 32 bits of the security key
    App_SecurityKey = App_SecurityKey << 32 | eeprom_read_dword(&eeSecurityKeyL);   //read last 32 bits of the security key
    App_ShortAddr = eeprom_read_word(&eeShortAddr);
    App_PanID = eeprom_read_word(&eeDefaultPan);
    App_Channel = eeprom_read_byte(&eeDefaultChannel);
	
	if (eeprom_read_word(&eeIdentity) != 0)
	{
		App_Identity = eeprom_read_word(&eeIdentity);
	}
	
	else
	{
		App_Identity = PHY_RandomReq();
		if (eeprom_is_ready())
		{
			eeprom_update_word((uint16_t*)&eeIdentity, App_Identity);
		}
	}

    NWK_SetAddr(App_ShortAddr);
	NWK_SetPanId(App_PanID);
	PHY_SetChannel(App_Channel);
	PHY_SetRxState(true);

#ifdef NWK_ENABLE_SECURITY
	NWK_SetSecurityKey((uint8_t *)App_SecurityKey);
#endif
	NWK_OpenEndpoint(APP_ENDPOINT, appDataInd);

    appDBTTimer.interval = 10000; //read temperature every 10s. Update temperature data every 180s.
    appDBTTimer.mode = SYS_TIMER_PERIODIC_MODE;
    appDBTTimer.handler = appDBTTimerHandler;
	
	appLSDebounceTimer.interval = 1;
	appLSDebounceTimer.mode = SYS_TIMER_PERIODIC_MODE;
	appLSDebounceTimer.handler = appLSDebounceTimerHandler;
 
    appALSTimer.interval = 1000;
    appALSTimer.mode = SYS_TIMER_PERIODIC_MODE;
    appALSTimer.handler = appALSTimerHandler;
	
	appRTCTimer.interval = 1000;
	appRTCTimer.mode = SYS_TIMER_PERIODIC_MODE;
	appRTCTimer.handler = appRTCTimerHandler;
	
	appAsyncJoinTimer.interval = 500 + App_ShortAddr;
	appAsyncJoinTimer.mode = SYS_TIMER_INTERVAL_MODE;
	appAsyncJoinTimer.handler = appAsyncJoinTimerHandler;
	
	appAsyncJoinChainResetTimer.interval = 0xffff;
	appAsyncJoinChainResetTimer.mode = SYS_TIMER_INTERVAL_MODE;
	appAsyncJoinChainResetTimer.handler = appAsyncJoinChainResetTimerHandler;
   
	SYS_TimerStart(&appRTCTimer);	//time starts ticking
    SYS_TimerStart(&appLSDebounceTimer);
	
	if (eeprom_read_byte(&eeSysJoined) == 1)
	{	
		if (!SYS_TimerStarted(&appDBTTimer))
		{
			SYS_TimerStart(&appDBTTimer);
		}
		
		if (!SYS_TimerStarted(&appALSTimer))
		{
			SYS_TimerStart(&appALSTimer);
		}
		
		LSConnectedMode = true;	
	}
 
	#ifdef PHY_ENABLE_RANDOM_NUMBER_GENERATOR
	  srand(PHY_RandomReq());
	#endif
	appState=APP_STATE_IDLE;
}

/*************************************************************************//**
*****************************************************************************/
static void APP_TaskHandler(void)
{
  switch (appState)
  {
    case APP_STATE_INITIAL:
	{
		appInit();
		break;
	}
	case APP_STATE_SEND:
	{
		appSendData(dst_node, APP_ENDPOINT, APP_ENDPOINT);
		appState = APP_STATE_IDLE;
		break;
	}
		
	case APP_STATE_BROADCAST:
	{
		appBroadcastData(APP_ENDPOINT, APP_ENDPOINT);
		appState = APP_STATE_IDLE;
		break;
	}
		
	case APP_STATE_LS_TOGGLE:
	{
		LSRemoteToggle = true;
		break;
	}
		
	case APP_STATE_LS_ON:
	{
		if (LSToggleState == false) //if light switch is OFF
		{
			LSRemoteToggle = true;	//toggle light switch
		}
		break;
	}
		
	case APP_STATE_LS_OFF:
	{
		if (LSToggleState == true)	//if light switch is ON
		{
			LSRemoteToggle = true;	//toggle light switch
		}
		break;
	}
		
	case APP_STATE_PUSH_CLIMATE:
	{
		CMDPushClimate();
		break;
	}
		
	case APP_STATE_PUSH_BRIGHTNESS:
	{
		CMDPushBrightness();
		break;
	}
		
	case APP_STATE_PUSH_LS_STATE:
	{
		CMDPushLSState();
		break;
	}
	
	case APP_STATE_IDLE:
	{
		LSStateMachine();
		CMDDataIOStateMachine();
		//SYNCStateMachine();
		break;
	}
		
    default:
	{
      break;
	}
  }
}
/*************************************************************************//**
*****************************************************************************/
int main(void)
{
	SYS_Init();
	AdcInit();
  
	//settings for pre-production units
	DDRE = (0 << PORTE7) | (1 << PORTE4);
	PORTE = (1 << PORTE7) | (0 << PORTE4);
  
	sei();	//Enable global interrupts
  
	ADCSRA |= 1 << ADSC;	//start ADC conversion
  
	SystemSettingsSet();
	while (1)
	{
	SYS_TaskHandler();
	//HAL_UartTaskHandler();
	APP_TaskHandler();
	}  
}

ISR(ADC_vect)	//interrupt routine for ADC
{
	switch(ADMUX){
		case 0x40:	//ADC input channel 0
			//ADC_GET_RAW_TEMP();	//get PIR
			ADMUX = 0x41;	//change ADC input to channel 1
			break;
		case 0x41:	//ADC input channel 1
			ADC_GET_RAW_LIGHT();	//get 10 bit temperature
			ADMUX = 0x42;	//change ADC input to channel 2
			break;
		case 0x42:	//ADC input channel 2
			ADC_GET_RAW_TEMP();	//get 10 bit light
			ADMUX=0x41;	//change ADC input to channel 1
			break;
		default:
			break;
	}
	ADCSRA |= 1<<ADSC;	//start the next ADC conversion
}


void SYNCStateMachine(void)
{
	if (LSSyncMode == true)
	{
		//led[1].r=0; led[1].g=0; led[1].b=36;
		//ws2812_setleds(led,2);
		//LSConnectedMode = true;
	}
	else
	{
		//led[1].r=0; led[1].g=0; led[1].b=0;
		//ws2812_setleds(led,2);
	}
}

void SystemSettingsSet(void)
{
	LSRemoteModeSet();
	//LSSlaveModeGet();
}

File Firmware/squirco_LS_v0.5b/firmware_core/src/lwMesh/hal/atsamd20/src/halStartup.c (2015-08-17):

/**
 * \file halStartup.c
 *
 * \brief ATSAMD20 startup code
 *
 * Copyright (C) 2012-2014, Atmel Corporation. All rights reserved.
 *
 * \asf_license_start
 *
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
 * 3. The name of Atmel may not be used to endorse or promote products derived
 *    from this software without specific prior written permission.
 *
 * 4. This software may only be redistributed and used in connection with an
 *    Atmel microcontroller product.
 *
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
 * \asf_license_stop
 *
 * Modification and other use of this code is subject to Atmel's Limited
 * License Agreement (license.txt).
 *
 * $Id: halStartup.c 9267 2014-03-18 21:46:19Z ataradov $
 *
 */

/*- Includes ---------------------------------------------------------------*/
#include <unistd.h>

/*- Definitions ------------------------------------------------------------*/
#define DUMMY         __attribute__ ((weak, alias ("HAL_IrqHandlerDummy")))

/*- Variables --------------------------------------------------------------*/
extern void _stack_top(void);
extern unsigned int _etext;
extern unsigned int _data;
extern unsigned int _edata;
extern unsigned int _bss;
extern unsigned int _ebss;

/*- Prototypes -------------------------------------------------------------*/
void HAL_IrqHandlerReset(void);
DUMMY void HAL_IrqHandlerNmi(void);
DUMMY void HAL_IrqHandlerHardFault(void);
DUMMY void HAL_IrqHandlerSvCall(void);
DUMMY void HAL_IrqHandlerPendSv(void);
DUMMY void HAL_IrqHandlerSysTick(void);

DUMMY void HAL_IrqHandlerPm(void);
DUMMY void HAL_IrqHandlerSysctrl(void);
DUMMY void HAL_IrqHandlerWdt(void);
DUMMY void HAL_IrqHandlerRtc(void);
DUMMY void HAL_IrqHandlerEic(void);
DUMMY void HAL_IrqHandlerNvmctrl(void);
DUMMY void HAL_IrqHandlerEvsys(void);
DUMMY void HAL_IrqHandlerSercom0(void);
DUMMY void HAL_IrqHandlerSercom1(void);
DUMMY void HAL_IrqHandlerSercom2(void);
DUMMY void HAL_IrqHandlerSercom3(void);
DUMMY void HAL_IrqHandlerSercom4(void);
DUMMY void HAL_IrqHandlerSercom5(void);
DUMMY void HAL_IrqHandlerTc0(void);
DUMMY void HAL_IrqHandlerTc1(void);
DUMMY void HAL_IrqHandlerTc2(void);
DUMMY void HAL_IrqHandlerTc3(void);
DUMMY void HAL_IrqHandlerTc4(void);
DUMMY void HAL_IrqHandlerTc5(void);
DUMMY void HAL_IrqHandlerTc6(void);
DUMMY void HAL_IrqHandlerTc7(void);
DUMMY void HAL_IrqHandlerAdc(void);
DUMMY void HAL_IrqHandlerAc(void);
DUMMY void HAL_IrqHandlerDac(void);
DUMMY void HAL_IrqHandlerPtc(void);

void HAL_IrqHandlerDummy(void);

extern int main(void);

__attribute__ ((section(".vectors")))
void (* const vectors[])(void) =
{
  &_stack_top,                   // 0 - Initial Stack Pointer Value

  // Cortex-M0+ handlers
  HAL_IrqHandlerReset,           // 1 - Reset
  HAL_IrqHandlerNmi,             // 2 - NMI
  HAL_IrqHandlerHardFault,       // 3 - Hard Fault
  0,                             // 4 - Reserved
  0,                             // 5 - Reserved
  0,                             // 6 - Reserved
  0,                             // 7 - Reserved
  0,                             // 8 - Reserved
  0,                             // 9 - Reserved
  0,                             // 10 - Reserved
  HAL_IrqHandlerSvCall,          // 11 - SVCall
  0,                             // 12 - Reserved
  0,                             // 13 - Reserved
  HAL_IrqHandlerPendSv,          // 14 - PendSV
  HAL_IrqHandlerSysTick,         // 15 - SysTick

  // Peripheral handlers
  HAL_IrqHandlerPm,              // 0 - Power Manager
  HAL_IrqHandlerSysctrl,         // 1 - System Controller
  HAL_IrqHandlerWdt,             // 2 - Watchdog Timer
  HAL_IrqHandlerRtc,             // 3 - Real Time Counter
  HAL_IrqHandlerEic,             // 4 - External Interrupt Controller
  HAL_IrqHandlerNvmctrl,         // 5 - Non-Volatile Memory Controller
  HAL_IrqHandlerEvsys,           // 6 - Event System
  HAL_IrqHandlerSercom0,         // 7 - Serial Communication Interface 0
  HAL_IrqHandlerSercom1,         // 8 - Serial Communication Interface 1
  HAL_IrqHandlerSercom2,         // 9 - Serial Communication Interface 2
  HAL_IrqHandlerSercom3,         // 10 - Serial Communication Interface 3
  HAL_IrqHandlerSercom4,         // 11 - Serial Communication Interface 4
  HAL_IrqHandlerSercom5,         // 12 - Serial Communication Interface 5
  HAL_IrqHandlerTc0,             // 13 - Timer/Counter 0
  HAL_IrqHandlerTc1,             // 14 - Timer/Counter 1
  HAL_IrqHandlerTc2,             // 15 - Timer/Counter 2
  HAL_IrqHandlerTc3,             // 16 - Timer/Counter 3
  HAL_IrqHandlerTc4,             // 17 - Timer/Counter 4
  HAL_IrqHandlerTc5,             // 18 - Timer/Counter 5
  HAL_IrqHandlerTc6,             // 19 - Timer/Counter 6
  HAL_IrqHandlerTc7,             // 20 - Timer/Counter 7
  HAL_IrqHandlerAdc,             // 21 - Analog-to-Digital Converter
  HAL_IrqHandlerAc,              // 22 - Analog Comparator
  HAL_IrqHandlerDac,             // 23 - Digital-to-Analog Converter
  HAL_IrqHandlerPtc,             // 24 - Peripheral Touch Controller
};

/*- Implementations --------------------------------------------------------*/

/*************************************************************************//**
*****************************************************************************/
void HAL_IrqHandlerReset(void)
{
  unsigned int *src, *dst;

  src = &_etext;
  dst = &_data;
  while (dst < &_edata)
    *dst++ = *src++;

  dst = &_bss;
  while (dst < &_ebss)
    *dst++ = 0;

  main();
  while (1);
}

/*************************************************************************//**
*****************************************************************************/
void HAL_IrqHandlerDummy(void)
{
  while (1);
}

/*************************************************************************//**
*****************************************************************************/
void _exit(int status)
{
  (void)status;
  while (1);
}

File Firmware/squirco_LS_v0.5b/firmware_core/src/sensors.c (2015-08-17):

#include "sensors.h"
#include "globalDefs.h"

//ADC Variables
volatile uint16_t ADC_ALS_LUX;
volatile uint16_t ADC_TEMP_C;
volatile uint16_t ADC_RAW_TEMP = 0;
volatile uint16_t ADC_RAW_LIGHT = 0;
const uint8_t ADCTemperatureBufferSize = 17;   //index starts at 0; 18 positions
volatile uint8_t ADCTemperatureBufferPosition = 0;

volatile uint16_t ADCPreviousTemperature;
volatile uint16_t ADCCurrentTemperature;

volatile uint16_t ADCPreviousLight;
volatile uint16_t ADCCurrentLight;
volatile uint16_t ADCPreviousLightStep;
volatile uint16_t ADCCurrentLightStep;
volatile uint16_t ADCPreviousLightPerception;
volatile uint16_t ADCCurrentLightPerception;

//ADC arrays
uint16_t ADCRawTemperatureBuffer[18];

void ADC_GET_AMBIENT_LIGHT(void)
{
	ADCPreviousLightStep = ADCCurrentLightStep;
	ADCPreviousLightPerception = ADCCurrentLightPerception;
	
	ADCCurrentLightPerception = pgm_read_word(&ALSLux[ADC_RAW_LIGHT][2]);
	ADCCurrentLightStep = pgm_read_word(&ALSLux[ADC_RAW_LIGHT][1]);
	ADCCurrentLight = pgm_read_word(&ALSLux[ADC_RAW_LIGHT][0]);	//IMPORTANT: update current light LAST!
	
	if ((abs(ADCPreviousLightPerception-ADCCurrentLightPerception) > 10 || (abs(ADCPreviousLightPerception-ADCCurrentLightPerception) > 2 && abs(ADCPreviousLightStep-ADCCurrentLightStep) >0)))
	{
		CommandsInBuffer[CommandsInIndexEnd][0] = 0x0182;	//get incoming command ID
		CommandsInBuffer[CommandsInIndexEnd][1] = 0;	//get incoming node address
		CommandsInIndexEnd++;
		if (CommandsInIndexEnd == CommandsInIndexSize)
		{
			CommandsInIndexEnd=0;
		}
		appState = APP_STATE_IDLE;
	}
	
}
void ADC_GET_TEMPERATURE(void)
{
	if(ADCTemperatureBufferPosition == ADCTemperatureBufferSize)	//if buffer is filled
	{
		ADCPreviousTemperature = ADCCurrentTemperature;
		ADCCurrentTemperature = 0;
		for (uint8_t index = 0; index < ADCTemperatureBufferSize; index++)   //calculate average
		{
			ADCCurrentTemperature += ADCRawTemperatureBuffer[index] / (ADCTemperatureBufferSize + 1);	//averaging values
		}
		
		if (ADCCurrentTemperature >= NTCMin && ADCCurrentTemperature <= NTCMax)	//if the average temperature is in the valid range
		{
			ADCCurrentTemperature = pgm_read_word(&NTCTemp[ADCCurrentTemperature - NTCMin]);	//set internal temperature tracker
		}
		
		ADCTemperatureBufferPosition = 0;	//reset buffer counter
		
		if (abs(ADCCurrentTemperature-ADCPreviousTemperature) >= 1)// && LSConnectedMode == true)
		{
			CommandsInBuffer[CommandsInIndexEnd][0] = 0x0181;	//get incoming command ID
			CommandsInBuffer[CommandsInIndexEnd][1] = 0;	//get incoming node address
			CommandsInIndexEnd++;
			if (CommandsInIndexEnd == CommandsInIndexSize)
			{
				CommandsInIndexEnd=0;
			}
			
			appState=APP_STATE_IDLE;	//send to hub
		}
		
	}
	else
	{
		ADCRawTemperatureBuffer[ADCTemperatureBufferPosition] = ADC_RAW_TEMP;
		ADCTemperatureBufferPosition++;
	}
}

void ADC_GET_RAW_TEMP(void)
{
	ADC_RAW_TEMP = ADCL | (ADCH << 8);
}

void ADC_GET_RAW_LIGHT(void)
{
	ADC_RAW_LIGHT = ADCL | (ADCH << 8);
}

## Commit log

2015-06-08 3D Enclosure Files
2015-06-08 Revert "3D Enclosure Files"
    This reverts commit 6feb40abfe3c21414d5d52db9328c61a6ee889bb.
2015-06-08 Logic and Power
    [Squirco Power v1.0.brd, Squirco Power v1.0.sch]
2015-06-08 Logic Board v1.0
    [Squirco Logic v1.0.brd, Squirco Logic v1.0.sch]
2015-06-08 Power Board v1.0
    [Squirco Power v1.0.brd, Squirco Power v1.0.sch]
2015-06-08 3D Files Added
    [Squirco Sensor Node - Backplate.STL, Squirco Sensor Node - Box.STL, Squirco Sensor Node - Button.STL]
2015-06-08 Button and ALS added
    [Ambient Light Sensor.brd, Ambient Light Sensor.sch, Button - Single.brd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]
2015-06-20 Added Programming Adaptor
    [Programming Adaptor v5.0.brd, Programming Adaptor v5.0.sch]
2015-06-21 Merge remote-tracking branch 'origin/master'
    Conflicts:
    Hardware-Extras/README.md
    [Squirco Logic v1.0.brd, Squirco Logic v1.0.sch]
2015-06-21 Added BOM

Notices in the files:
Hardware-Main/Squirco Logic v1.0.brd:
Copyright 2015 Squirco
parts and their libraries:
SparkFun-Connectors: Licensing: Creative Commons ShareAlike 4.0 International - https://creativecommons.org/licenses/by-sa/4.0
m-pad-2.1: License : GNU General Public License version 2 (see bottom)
